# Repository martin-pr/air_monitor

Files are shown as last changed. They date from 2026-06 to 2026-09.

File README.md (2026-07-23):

# air_monitor
ESP32-based air monitor (CO2, temperature, humidity) with BLE notifications.
Ships in two firmware variants that share the sensor, BLE beacon protocol,
and Android widget:

- **display** — v1 hardware: e-paper dashboard, per-cycle full readout, charging inferred from battery voltage.
- **led** — v2 hardware: RGB status LED, momentary button, explicit USB charging detection. No display.

## Hardware

Shared across both variants:

- Seeed Studio XIAO ESP32-C3
- Sensirion SCD41 (CO2 / temperature / humidity, I2C)
- LiPo cell (400 mAh reference) with a 220 k / 220 k battery-voltage divider into `D0`

Display variant additionally uses:

- WeAct 200×200 ePaper module (SPI, SSD1681)

LED variant additionally uses:

- 5050 RGB LED (common-cathode assumed), three GPIO PWM channels through per-channel current-limiting resistors — 220 Ω red, 47 Ω green, 47 Ω blue
- Momentary push-button between a GPIO and GND, wired as a deep-sleep wake source
- VBUS-to-GPIO voltage divider for explicit "USB plugged in" detection (see wiring below)

## Prerequisites (one-time)

Install arduino-cli (official 64-bit binary, not the snap):

```bash
curl -fsSL https://raw.githubusercontent.com/arduino/arduino-cli/master/install.sh | sh
```

Install the ESP32 board package and required libraries:

```bash
arduino-cli core update-index
arduino-cli core install esp32:esp32
arduino-cli lib install "Sensirion I2C SCD4x"
# display variant only:
arduino-cli lib install GxEPD2
arduino-cli lib install "Adafruit GFX Library"
```

Grant serial port access:

```bash
sudo usermod -aG dialout $USER
# then log out and back in, or use: sg dialout -c "<command>"
```

## Build & Flash

```bash
cd firmware
cmake -B build
```

Build one variant, or both:

```bash
cmake --build build --target build_display
cmake --build build --target build_led
cmake --build build             # both variants
```

Flash to the device:

```bash
cmake --build build --target flash_display
cmake --build build --target flash_led
```

To override the upload port or target a different board:

```bash
cmake -B build -DPORT=/dev/ttyACM1
cmake -B build -DFQBN=esp32:esp32:XIAO_ESP32S3
```

The default FQBN is `esp32:esp32:XIAO_ESP32C3`.

### Source layout

```
firmware/
├── common/          Arduino library shared by both variants
│   └── src/         battery, ble, reset_reason, sensor
├── display/         e-paper sketch (display.ino, app.cpp, display.cpp)
└── led/             LED sketch (led.ino, app.cpp, plus led/button/charging modules)
```

## Serial Monitor

```bash
arduino-cli monitor -p /dev/ttyACM0 -c baudrate=115200
```

Press Enter once after connecting — the USB-Serial-JTAG peripheral requires the host to send a byte before output appears. This is default arduino-esp32 3.x behavior.

## Android Widget

The `app` directory contains an Android home-screen widget. It passively scans for BLE advertisements from the device and displays the latest sensor readings — no connection or pairing required.

The build uses Gradle with the Android Gradle Plugin. The wrapper is checked in, so no system Gradle install is needed — just JDK 17 and the Android SDK (build-tools 35, platform android-35). Point `local.properties` at the SDK on first checkout:

```bash
cd app
echo "sdk.dir=$HOME/Android/Sdk" > local.properties
```

Build the debug APK:

```bash
./gradlew :app:assembleDebug
# → app/build/outputs/apk/debug/app-debug.apk
```

Build the release AAB (for Google Play upload):

```bash
./gradlew :app:bundleRelease
# → app/build/outputs/bundle/release/app-release.aab
```

Release signing is driven by `keystore.properties` at the repo root (git-ignored). When it's present and points at an upload keystore, release builds are signed with it; when it's absent, they fall back to the debug keystore — fine for local test builds but rejected by Play.

Install a debug build on a connected Android device:

```bash
adb install -r app/build/outputs/apk/debug/app-debug.apk
```

After installing, add the **Air Monitor** widget from the Android launcher widget picker.

## BLE

The device uses a **connectionless beacon** — no GATT, no pairing. It wakes from deep sleep every 5 minutes, takes a measurement, updates the display (display variant) or flashes the status LED (LED variant), then advertises for 5 seconds before going back to sleep.

The advertisement contains manufacturer-specific data with company ID `0x4D41` (`AM`, little-endian bytes `0x41 0x4D`), followed by a versioned binary payload:

| Byte offset (after company ID) | Field | Type | Notes |
|---|---|---|---|
| 0 | Protocol version | uint8 | Currently `1`; check before parsing further fields |
| 1 | Status | uint8 | Last `esp_reset_reason_t`. `8` = normal wake from deep sleep; any other value means the chip cold-booted (see table below) |
| 2–3 | CO2 | uint16 LE | ppm |
| 4–5 | Temperature | int16 LE | 0.01 °C (e.g. 2350 = 23.50 °C) |
| 6 | Relative humidity | uint8 | % RH (integer) |
| 7 | Battery | uint8 | `0–100` = battery %; `0xFF` = charging. Detected via Vbat > 4.10 V threshold (display variant) or an explicit VBUS-divider ADC (LED variant); the % is unreliable during a charge cycle so we send a sentinel instead |

**Parsing rule:** read byte 0 first; only parse further fields if the version is known. The protocol is still under development — the version byte is bumped on any layout change rather than maintaining backward compatibility.

#### Status (reset reason) values

The raw `esp_reset_reason_t` enum is exposed as-is. The interesting values for this firmware:

| Value | Name | Meaning |
|---|---|---|
| 0 | `ESP_RST_UNKNOWN` | Reason could not be determined |
| 1 | `ESP_RST_POWERON` | Cold boot — USB plugged in, battery connected, or RESET button |
| 3 | `ESP_RST_SW` | Software-triggered `esp_restart()` (not used by this firmware) |
| 4 | `ESP_RST_PANIC` | Firmware crash (exception / abort) |
| 5 | `ESP_RST_INT_WDT` | Interrupt watchdog fired |
| 6 | `ESP_RST_TASK_WDT` | FreeRTOS task watchdog fired |
| 7 | `ESP_RST_WDT` | RTC watchdog (other) |
| 8 | `ESP_RST_DEEPSLEEP` | **Normal** — woke from `esp_deep_sleep()` |
| 9 | `ESP_RST_BROWNOUT` | Vbat sagged below the brownout threshold |
| 11 | `ESP_RST_USB` | USB peripheral triggered reset |
| 12 | `ESP_RST_JTAG` | JTAG triggered reset |

Values not in this table can still appear (`ESP_RST_EFUSE = 13`, `ESP_RST_PWR_GLITCH = 14`, `ESP_RST_CPU_LOCKUP = 15`, `ESP_RST_SDIO = 10`, `ESP_RST_EXT = 2`) — they're unlikely on this hardware/firmware but should be passed through unchanged.

The device advertises as **Air Monitor** (MAC `ac:27:6e:7e:c7:f4`). Scanners can filter by local name or company ID.

## Wiring

### SCD41 (I2C) — both variants

| SCD41 pin | XIAO pin | GPIO |
|---|---|---|
| VDD | 3V3 | — |
| GND | GND | — |
| SDA | D4 | GPIO6 |
| SCL | D5 | GPIO7 |

A decoupling capacitor between VDD and GND is required for stable CO2 readings. The NDIR laser draws a brief high current spike; without sufficient capacitance the CO2 measurement fails while RH/temp continue to work. The tested working combination is a 10 µF ceramic and a 100 µF electrolytic in parallel.

### Battery (J1 + voltage divider) — both variants

A JST connector (J1) brings in the LiPo battery. Two 220 kΩ resistors (R1, R2) form a 1:2 voltage divider so the full battery voltage range fits within the ESP32-C3 ADC input range:

```
Battery+ ──[R2 220kΩ]──┬── D0 (GPIO2, ADC)
                        │
                    [R1 220kΩ]
                        │
                       GND
```

Read with ADC 11 dB attenuation (0–3.9 V input range). The quiescent current through the divider is 4.2 V / 440 kΩ ≈ 10 µA — negligible.

Voltage is converted to a battery percentage using a 4-point lookup table with linear interpolation between segments:

| % | Battery V | V at D0 |
|---|---|---|
| 100 | 4.20 | 2.10 |
| 80 | 3.98 | 1.99 |
| 20 | 3.52 | 1.76 |
| 0 | 3.00 | 1.50 |

The middle segment (20–80%) approximates the flat part of the LiPo discharge curve; the steeper drops at each end get their own segments.

### ePaper Display (SPI) — display variant only

The WeAct 200×200 module connects over SPI. Despite the silkscreen labels (SCL/SDA), these are SPI signals — not I2C.

| WeAct pin | XIAO pin | GPIO |
|---|---|---|
| VCC | 3V3 | — |
| GND | GND | — |
| SDA | D10 | GPIO10 (MOSI) |
| SCL | D8 | GPIO8 (SCK) |
| CS | D3 | GPIO5 |
| D/C | D2 | GPIO4 |
| RES | D1 | GPIO3 |
| BUSY | D6 | GPIO21 |

Pins D7 and D9 remain free after this wiring.

The display is driven by [GxEPD2](https://github.com/ZinggJM/GxEPD2) using the `GxEPD2_154_D67` driver class.

### RGB LED (PWM) — LED variant only

A common-cathode 5050 RGB LED, one GPIO per channel, driven by ESP32-C3 LEDC PWM. Per-channel current-limiting resistors size the drive current so R / G / B contribute roughly equally at equal duty:

| Channel | XIAO pin | Series R | Current at full duty | Notes |
|---|---|---|---|---|
| Red | D6 | 220 Ω | ~5.9 mA | V_f ≈ 2.0 V, plenty of headroom |
| Green | D3 | 47 Ω  | ~6.4 mA | V_f ≈ 3.0 V, current sensitive to part-to-part V_f drift |
| Blue  | D2 | 47 Ω  | ~6.4 mA | Same as green |

```
D6 ──[220 Ω]── R anode ──┐
D3 ──[47 Ω] ── G anode ──┼── common cathode ── GND
D2 ──[47 Ω] ── B anode ──┘
```

Firmware never drives at 100 % duty — LED is used for brief low-brightness status flashes. Average current is deep-sleep-noise level, so no need to worry about brownout on turn-on transients.

### Button — LED variant only

Momentary tactile switch from a GPIO to GND, with the internal pull-up enabled on that pin. Wired as an RTC-capable pin so a press wakes the chip from deep sleep.

```
D7 ──┬── button ── GND
      │
      └── (internal pull-up)
```

### Charging-detect divider — LED variant only

Rather than inferring charging from Vbat > 4.10 V (the display variant's approach), the LED board has a dedicated divider off USB VBUS into a second ADC pin. VBUS is 5 V when USB is plugged in, 0 V otherwise; a 220 k / 220 k divider brings that to ~2.5 V, easily distinguished from 0 V by an ADC read.

```
VBUS ──[220 kΩ]──┬── D1 (GPIO3, ADC)
                  │
              [220 kΩ]
                  │
                 GND
```

Same resistor values as the battery divider — one BOM entry, shared design.

## Power

### Architecture

Both variants use a **deep sleep beacon** cycle:

1. Wake from deep sleep (timer, or button press on LED variant)
2. Take SCD41 single-shot measurement (~5 s)
3. Update display (display variant) or flash status LED (LED variant)
4. Advertise BLE beacon for 5 s
5. Deep sleep for ~5 minutes

Total active time: ~11 s per 300 s cycle.

### Component current

| Component | Mode | Current |
|---|---|---|
| ESP32-C3 | Deep sleep | ~5 µA |
| ESP32-C3 | Active, 80 MHz, no radio | ~20 mA |
| ESP32-C3 | BLE advertising burst | ~30 mA peak |
| SCD41 | Single-shot (5 min interval average) | ~0.5 mA |
| SCD41 | Power-down | <0.001 mA |
| ePaper (display variant) | Update (active) | ~20 mA |
| ePaper (display variant) | Hibernate | <0.01 mA |
| RGB LED (LED variant) | ~10 % duty, brief flash | ~2 µA averaged over the 5 min cycle |

### Battery estimate (400 mAh cell)

Active ~11 s per 300 s cycle, deep sleep otherwise. Averaged over a full cycle:

- ESP32-C3 active: ~25 mA × (11/300) ≈ 0.9 mA
- SCD41 single-shot: ~0.5 mA average (per datasheet at 5 min interval)
- Deep sleep (everything): ~5 µA × (289/300) ≈ negligible
- Display refresh (display variant only): dominated by ESP32-C3 active time, not the ePaper itself
- LED signalling (LED variant only): negligible (~2 µA averaged)

**Total ≈ 1.4 mA average → ~12 days on 400 mAh** for either variant (excluding deep sleep current anomalies under investigation). The LED variant should be marginally better since ePaper refresh time shrinks to zero, but the ESP32-C3 active window still dominates the budget.

### SCD41 single-shot and ASC

The firmware uses `measure_single_shot` (not periodic mode). The sensor stays idle until triggered, takes ~5 s for a reading, then enters power-down. The ESP32 controls the interval.

Automatic Self-Calibration (ASC) works with single-shot via the `power_down` / `wake_up` command pair, which preserves calibration state in SRAM. Hard VDD power-cycling breaks ASC because SRAM is lost. The datasheet optimises ASC for a 5-minute interval and requires outdoor-level CO2 (~400 ppm) exposure at least once per week.

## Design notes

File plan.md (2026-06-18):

# Power Reduction Plan

## Target

- Battery: 450 mAh
- Required runtime: 2 weeks
- Average current budget: **1.34 mA**

## Why the current architecture cannot meet the target

The device currently averages ~50 mA with BLE always advertising. Even with every available always-on optimization, the math does not work:

| Architecture | Avg current | Battery life |
|---|---|---|
| Current (always-on BLE, no sleep) | 50 mA | ~9 hours |
| BLE modem sleep, fully tuned | 5-8 mA | 2-3 days |
| Deep sleep, 30s wake interval | ~4 mA | ~4 days |
| Deep sleep, 2 min wake interval | ~2 mA | ~9 days |
| Deep sleep, 5 min wake interval | ~1 mA | ~18 days |

The BLE controller on ESP32-C3 holds a `NO_LIGHT_SLEEP` pm lock while active, so any architecture that keeps BLE up continuously is bounded by the radio's idle current. Deep sleep between measurements is the only path that meets the budget.

Confirmed empirically: with `BLE_ENABLED = false` the device draws 22 mA (light sleep not engaging due to USB-JTAG pm lock); with BLE on, 50 mA. Neither is close to 1.34 mA.

## Chosen architecture: deep sleep + BLE beacon

1. Wake from deep sleep
2. Take SCD41 single-shot measurement (~5s)
3. Update e-paper display (~1.5s)
4. Emit advertising packets with reading encoded in manufacturer data (~5s)
5. Deep sleep for the remainder of the cycle (~5 µA)

Reading carried in the advertisement payload — no GATT connection needed. Phone scans and parses.

## Existing work: `beacon_mode` branch

This architecture is mostly implemented on the `beacon_mode` branch:

- `esp_deep_sleep()` with 1-minute cycles
- SCD41 single-shot mode with proper wake/measure/powerDown sequencing
- Manufacturer-data beacon: company ID `0x4D41` ('AM'), 7-byte versioned payload (version, CO2, temp×100, RH, battery%)
- 5-second advertising window at 100 ms interval
- `Wire.end()`, `SPI.end()`, GPIO10 floated before sleep
- Android app rewritten to scan-and-parse instead of connect-and-subscribe

## Open issues to resolve

### 1. ~~Display bug: empty after 2nd refresh~~ (fixed)

Fixed via `display.epd2.writeScreenBufferAgain()` after the initial clear plus the buffered `showStatus` rewrite. Plus `showStatus(rstMsg)` so the reset reason becomes line 1 in the buffer rather than being clobbered by the first status update.

### 2. Android background reception unreliable

The core blocker. A normal `startScan()` callback does not fire when the screen is off because of Android's Doze and background scan throttling. Three paths forward, in order of preference for a widget use case:

**Option A — PendingIntent-based scanning (API 26+).** Use the `BluetoothLeScanner.startScan(filters, settings, callbackIntent)` overload. The system holds the filter, scans on its own schedule, and wakes the app via the intent on a match — including from Doze.
- Pros: no foreground service, no persistent notification, designed for exactly this case.
- Cons: requires `ACCESS_BACKGROUND_LOCATION` on Android 10+. Some OEM power managers (Xiaomi, Huawei) kill it.
- Phone battery impact: **~0.5-1% per day**. The system batches scans and the app only wakes on match (once per sensor cycle); each wake is ~50-100 ms of CPU plus a brief intent dispatch.

**Option B — Foreground service with persistent notification.** A foreground service is exempt from Doze scanning restrictions; `startScan` callback runs continuously.
- Pros: most reliable across all OEMs.
- Cons: permanent status-bar notification.
- Phone battery impact: **~5-15% per day**. Continuous BLE scanning is expensive (BT subsystem stays in the 3-15 mA range depending on scan mode), and the service prevents the app process from being killed, so any callbacks/work executed per scan result accumulate.

**Option C — Connection-oriented with `autoConnect=true`.** Device wakes, advertises, accepts a short GATT connection, sends the reading, disconnects, sleeps. Phone uses `connectGatt(autoConnect=true)` which makes Android handle the wait-and-connect at the system level.
- Pros: very reliable on Android.
- Cons: device awake longer (~10-15s instead of ~5s), modestly higher average current.
- Phone battery impact: **~1-3% per day**. The system handles the pending-connection efficiently; brief radio activity (~1-2s per sensor cycle) when the device shows up.

Numbers are rough — actual impact varies with phone hardware, Android version, and other background scanners. For reference, a typical phone uses 0.5-1% per hour in standby, so option A or C adds noise-level overhead while option B is genuinely noticeable.

Decision pending. Current `BleWidgetService.java` (merged from beacon_mode) implements option B — foreground service with `SCAN_MODE_LOW_LATENCY` and `MATCH_MODE_AGGRESSIVE`. Confirmed unreliable when the screen is locked, so this implementation must change regardless. Option A or C is the way forward.

## Measured progress

All numbers measured on hardware: battery-powered, USB disconnected, average current over a steady-state 1-minute cycle (after first boot completes). `beacon_mode` has been merged into `main`.

| Firmware state | Avg current | Battery life | Per-cycle energy |
|---|---|---|---|
| Cherry-picked beacon_mode baseline | 8.8 mA | 2.1 days | 528 mAs |
| SCD41 5s wait → `esp_light_sleep_start()` (`df427b1`) | 7.74 mA | 2.4 days | 464 mAs |
| Drop `WiFi.mode(WIFI_OFF)` + 200ms delay | 7.33 mA | 2.55 days | 440 mAs |

Per-cycle active energy is ~380 mAs over a ~14 s active phase (about 27 mA average during active). The 5 s BLE advertising window is the largest single chunk.

### Sleep current is *not* negligible — 1.29 mA measured

Direct measurement of the deep-sleep floor: **1.29 mA**, three orders of magnitude higher than the ~5 µA the ESP32-C3 datasheet suggests. Isolation testing:

| Configuration | Sleep current |
|---|---|
| Full board (XIAO + display + SCD41 + battery divider) | 1.29 mA |
| Display module disconnected | 232 µA |
| → Display module contribution | **~1.06 mA** |

The e-paper module is drawing ~1 mA continuously during sleep despite `display.hibernate()` and `SPI.end()`. The SSD1681 chip itself in deep sleep is ~5 µA, so this is module-level circuitry on the breakout PCB (boost/charge-pump glue, level shifters, or leakage paths through floating data pins on the SSD1681). The remaining 232 µA floor (no display) is XIAO + SCD41 breakout + ESP32-C3's real-world deep-sleep being higher than datasheet — secondary concern.

### Battery-life projections must include sleep current

With sleep dominant at longer cycles, the math changes dramatically. Per-cycle energy = ~380 mAs active + sleep current × sleep duration:

| Cycle | Sleep at 1.29 mA (today) | Sleep at 232 µA (display power-gated) |
|---|---|---|
| 1 min | 7.33 mA → 2.55 d (measured) | ~6.5 mA → 2.9 d |
| 5 min | 2.50 mA → 7.5 d | 1.49 mA → 12.6 d |
| 6 min | 2.29 mA → 8.2 d | 1.28 mA → 14.7 d ✓ |
| 10 min | 1.89 mA → 9.9 d | 0.86 mA → 21.8 d |
| 15 min | 1.69 mA → 11.1 d | 0.65 mA → 28.8 d |
| ∞ (sleep only) | **1.29 mA → 14.5 d (ceiling)** | 0.232 mA → 80+ d |

**At 1.29 mA sleep, no cycle length reaches 2 weeks** — sleep current alone consumes the budget. The display power-gating must be solved before any cycle-tuning matters.

### Notes on optimizations attempted/considered

- `display.hibernate()` between updates: kept (still correct), but power impact was much smaller than the SSD1681 datasheet suggested. Most of the visible refresh time is the e-ink material settling at low current, not the voltage pump.
- Shortening `ADV_DURATION_MS` (5 s → 2 s): not yet applied — would save ~90 mAs/cycle but couples to the (still-undecided) Android reception strategy. Safe under foreground scanning (option B), risky under PendingIntent (option A) or short-window autoConnect (option C).
- CPU frequency dance (drop to 40 MHz outside the BLE phase): not applied. BLE requires ≥80 MHz on ESP32-C3; dropping for the non-BLE phase would save ~50 mAs/cycle but adds complexity (APB clock divides change, affecting SPI/I2C timing).
- `esp_bt_sleep_enable()` before advertising: not tried yet — unknown gain, low risk.

### Display sleep-current fix options

1. ~~**Software — float all display pins (CS, DC, RST, SCK, MOSI) before deep sleep.**~~ Tried, no effect (1.29 → 1.30 mA). Leakage is not through SSD1681 input pins.
2. ~~**Software — switch SSD1681 from deep sleep mode 1 to mode 2** (RAM not retained, deeper sleep).~~ Tried via raw SPI `0x10 0x11` after `hibernate()`, no effect (1.30 mA). Module-level leakage is independent of SSD1681 sleep depth.
3. ~~**Software — hold `EPD_RST` low through deep sleep via `gpio_hold_en()`**~~ on the chance the breakout's boost EN piggybacks off RST. Tried, *worse* (1.36 mA): the boost is not gated by RST, and holding the GPIO output + putting the chip in hardware reset both cost a small amount.

All three software paths confirmed dead. The module's quiescent draw is from its own onboard circuitry (boost converter / glue), independent of any SSD1681 pin or state. **Hardware power-gating is the only remaining option.**

4. **Hardware — high-side P-channel MOSFET load switch on the display VCC.** Gate driven by a GPIO; drive high to cut power before sleep, low to enable on wake. ~3 components (MOSFET + pull-up + GPIO). Fully power-gates the module → 0 µA from display in sleep. The only viable fix for the display variant.

5. **Build a no-display variant.** If the display isn't a hard requirement, omitting it sidesteps the problem entirely — no board revision needed. See below.

### Alternative: no-display variant meets the goal as-is

Removing the e-paper module entirely (or fitting a hardware variant without it) gives a 232 µA sleep floor with no further engineering. The active phase also drops by ~30–50 mAs/cycle (no display init / full-window refresh / hibernate).

Estimated active phase: ~340–360 mAs/cycle (vs ~380 mAs with display).

| Cycle | Avg current | Battery life |
|---|---|---|
| 1 min | ~6.0 mA | ~3 days |
| 5 min | ~1.40 mA | ~13.4 days |
| **6 min** | **~1.20 mA** | **~15.6 days ✓** |
| 10 min | ~0.81 mA | ~23 days |
| 15 min | ~0.60 mA | ~31 days |

A 6-minute cycle on the no-display variant hits 2 weeks with margin; 10-minute gives 3 weeks. Since there's no visual refresh, longer cycles are free — the phone gets readings from the beacon regardless of cadence.

The 232 µA floor still has ~225 µA of unexplained draw (vs ESP32-C3 datasheet ~5 µA deep sleep). Likely from the SCD41 breakout pull-ups and the C3's real-world deep sleep being higher than spec. Could be chased further but isn't needed for the 2-week target.

## Next steps

Two parallel paths depending on whether the display is a hard requirement:

**Display-required path:**
1. Design the MOSFET load switch on the next PCB revision (display VCC power-gated by a GPIO).
2. Once display sleep current is fixed, tune `SLEEP_DURATION_US` to the cycle length that meets the budget.

**No-display variant:**
1. Measure actual active-phase energy with the display removed to confirm the ~340-360 mAs estimate.
2. Set `SLEEP_DURATION_US` to 6 minutes (or longer for more margin).

**Both paths:**
3. Pick A / B / C for Android reception.
4. Implement chosen Android approach.

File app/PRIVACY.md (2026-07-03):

# Privacy Policy

**Last updated:** July 2, 2026

Air Monitor is an open-source Android home-screen widget for displaying
sensor readings from an ESP32-based air monitor.

The app passively scans for Bluetooth Low Energy (BLE) advertisements
from the device and displays the latest sensor readings. It does not
connect to, pair with, or transmit data to the device.

## Information Collection

Air Monitor does not collect, store, transmit, sell, or share personal
information.

The app does not use: - Analytics - Advertising - User accounts -
Tracking technologies - Backend servers - Firebase - Crashlytics - Cloud
services operated by the developer

## Local Operation

Any data shown by the app is received locally on the user's device from
nearby BLE advertisements and is used only to display air-monitor
readings.

## Google Play

The app is distributed through Google Play. Google may collect
information related to app download, installation, updates, crash
reporting, and Play Store usage under Google's own privacy policies. The
developer may only receive aggregated information made available through
Google Play Console.

## Open Source

Source code: https://github.com/martin-pr/air_monitor

## Contact

Questions or issues can be raised on the GitHub repository.

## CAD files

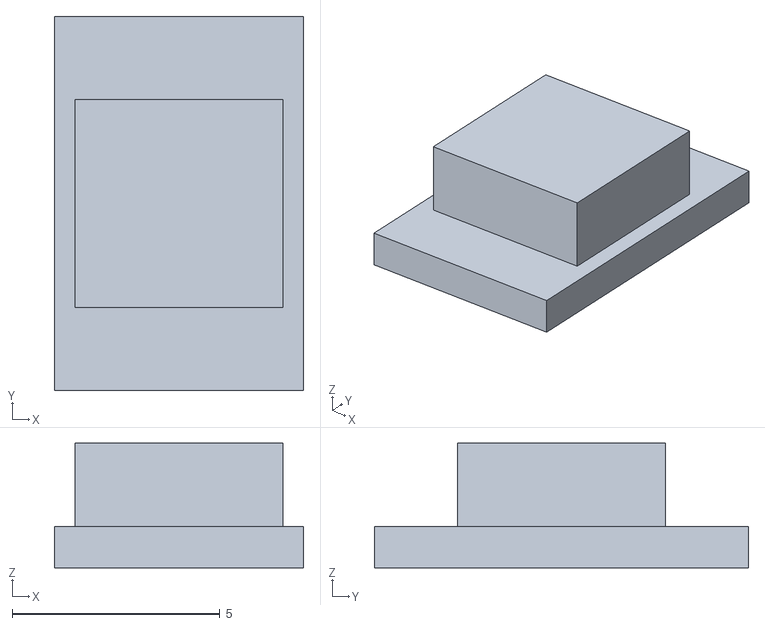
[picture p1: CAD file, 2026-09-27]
enclosure/enclosure_v2_windows.stl
6.00 x 9.00 x 3.00

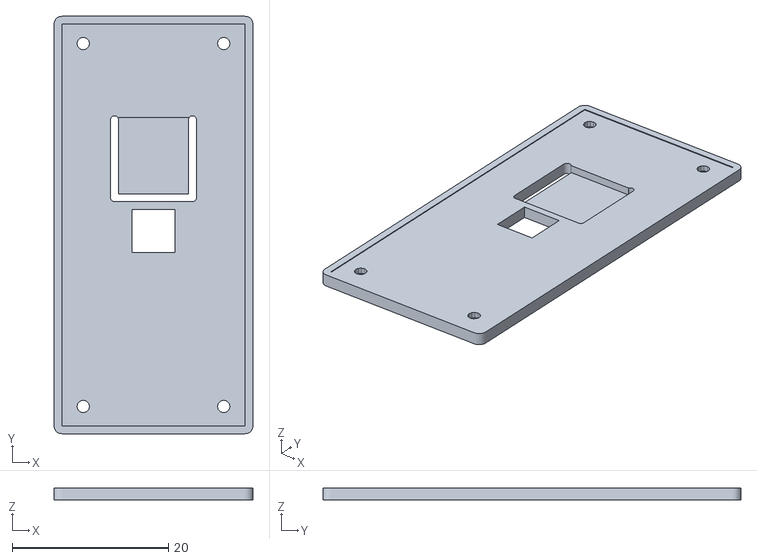
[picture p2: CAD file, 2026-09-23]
enclosure/enclosure_v2_top.stl
25.5 x 53.5 x 1.60

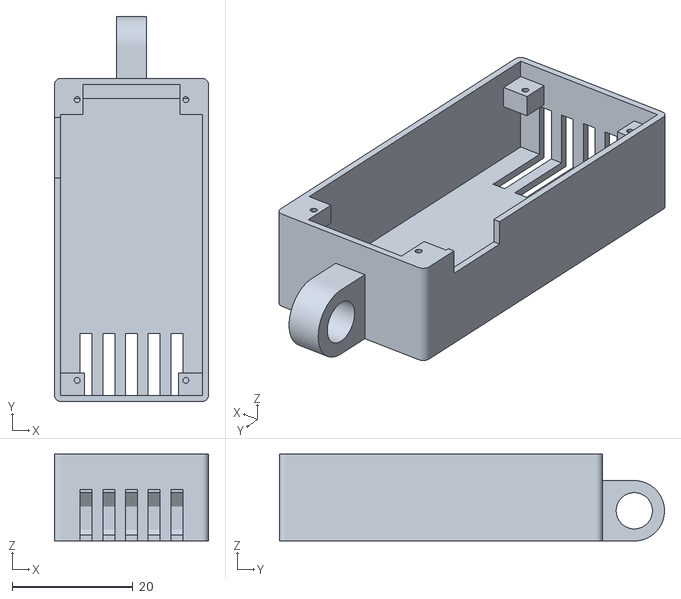
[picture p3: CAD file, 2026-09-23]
enclosure/enclosure_v2.stl
25.5 x 63.8 x 14.4

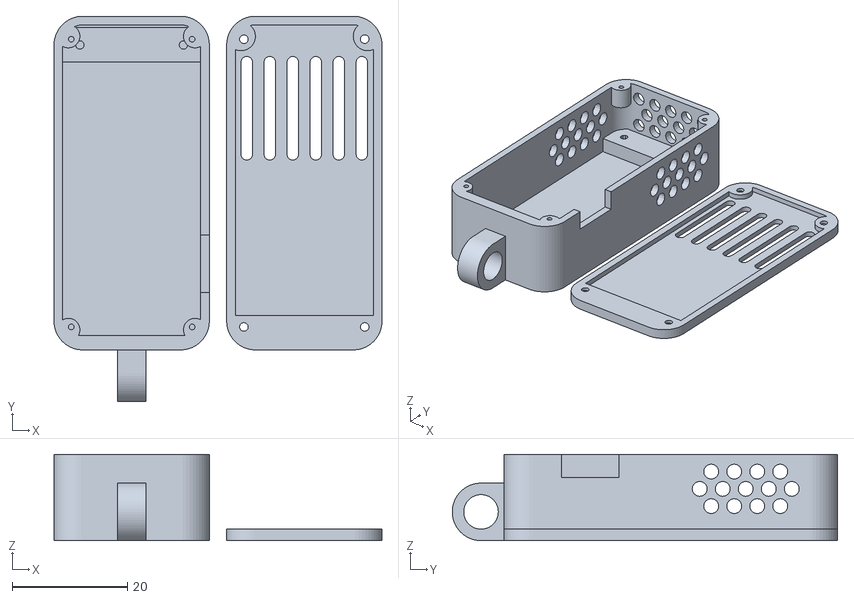
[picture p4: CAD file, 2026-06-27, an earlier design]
enclosure/enclosure.stl
57.0 x 67.0 x 15.0

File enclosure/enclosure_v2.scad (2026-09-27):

// 23.5 x 51.5r x 12

module bottom() union() {
    difference() {
        union() {
            minkowski() {
                cube([23.5, 51.5, 14], center=true);
                cylinder(d=2, h=2,  center=true, $fn=20);
            }        
        }
        
        cube([23.5, 51.5, 14], center=true);
        translate([0,0,9.4]) cube([26, 55, 6], center=true);
        
        translate([7.5,-23,-5]) cube([2, 15, 11], center=true);
        translate([3.75,-23,-5]) cube([2, 15, 11], center=true);
        translate([0,-23,-5]) cube([2, 15, 11], center=true);
        translate([-3.75,-23,-5]) cube([2, 15, 11], center=true);
        translate([-7.5,-23,-5]) cube([2, 15, 11], center=true);
        
        translate([-12,15.25,4.91]) cube([5,10,4], center=true);
    }

    translate([9,-23.25,2.5]) difference() {
        translate([1,-1,0]) cube([4.5, 4.5, 3], center=true);
        cylinder(r=0.5, h=20, center=true, $fn=12);
    }        

    translate([-9,-23.25,2.5]) difference() {
        translate([-1,-1,0]) cube([4.5, 4.5, 3], center=true);
        cylinder(r=0.5, h=20, center=true, $fn=12);
    }    

    translate([0,24,-3.5]) difference() {
        cube([25, 3.5, 7], center=true);
        translate([0,,-2]) rotate(45, [1,0,0]) cube([25, 7, 9], center=true);
    }    

    translate([0,23.25,5]) difference() {
        cube([25, 5, 2.8], center=true);
        translate([9,0,0]) cylinder(r=0.5, h=20, center=true, $fn=12);
        translate([-9,0,0]) cylinder(r=0.5, h=20, center=true, $fn=12);
        cube([16, 6, 3], center=true);
    }   
   
    translate([0,32,-3]) {
        difference() {
            hull() {
                rotate(90, [0,1,0]) cylinder(r=5, h=5, center=true, $fn=64);
                translate([0,-3,0]) cube([5,5,10], center=true);
            }
            
            rotate(90, [0,1,0]) cylinder(r=3, h=7, center=true, $fn=64);
        }
    }    
}

 module hole() {
     translate([0, 0, 7.75]) cylinder(r=1.5, h=1, center=true, $fn=12);
     translate([0, 0, 6.95]) cylinder(r=0.8, h=5, center=true, $fn=12);
 }

 //translate([40,-26.75,0]) cube([10,21,15]);
//translate([40,0,0]) translate([0,-26.75,0]) cube([10,27.5,15]);
// translate([40,0,0]) translate([0,0.75,0]) cube([5,5,15], center=true);

module corner() cylinder(d=1, h=5, center=true, $fn=32);

module top() difference() {
    intersection() {
        
        difference() {
            minkowski() {
                cube([23.5, 51.5, 14], center=true);
                cylinder(d=2, h=2,  center=true, $fn=20);
            }        
            cube([23.5, 51.5, 13], center=true);
        }
        translate([0,0,7.4]) cube([26, 55, 2], center=true);
    }
    
    translate([9,-23.25,0]) hole();
    translate([-9,-23.25,0]) hole();
    
    translate([0,23.25,0]) {
        translate([9,0,0]) hole();
        translate([-9,0,0]) hole();
    }

    translate([0,0.75,0]) cube([5.5,5.5,18], center=true);
    
    translate([0, -8.75, 0]) cube([10,10,15], center=true);
    
    translate([0, -3.5, 6.95]) hull() {
        translate([-5,0,0]) corner();
        translate([5,0,0]) corner();
    };

    translate([0, -3.5, 6.95]) hull() {
        translate([-5,0,0]) corner();
        translate([-5,-10,0]) corner();
    };
    
    translate([0, -3.5, 6.95]) hull() {
        translate([5,0,0]) corner();
        translate([5,-10,0]) corner();
    };
}

module led(size, rim_y=4, rim_x=1) union() {
    translate([-size/2, -size/2, 0]) cube([size,size,3]);
    translate([(-size-rim_x)/2, (-size-rim_y)/2, 0]) cube([size+rim_x,size+rim_y,1]);
}

// bottom();
// rotate(180, [1,0,0]) translate([20,0,-8]) top();

led(5);

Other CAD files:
enclosure/enclosure.scad

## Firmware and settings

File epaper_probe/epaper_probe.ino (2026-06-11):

#include <SPI.h>
#include <GxEPD2_BW.h>
#include <Fonts/FreeSans9pt7b.h>

#define EPD_CS   5
#define EPD_DC   4
#define EPD_RST  3
#define EPD_BUSY 21
#define SPI_SCK  8
#define SPI_MOSI 10
#define SPI_MISO 9

GxEPD2_BW<GxEPD2_154_D67, GxEPD2_154_D67::HEIGHT> display(
    GxEPD2_154_D67(EPD_CS, EPD_DC, EPD_RST, EPD_BUSY)
);

void drawTest(const char *label) {
    display.setFullWindow();
    display.firstPage();
    do {
        display.fillScreen(GxEPD_WHITE);
        display.setTextColor(GxEPD_BLACK);
        display.setFont(&FreeSans9pt7b);
        display.setCursor(10, 60);
        display.print("GxEPD2_154_D67");
        display.setCursor(10, 90);
        display.print(label);
        display.fillRect(10, 110, 180, 40, GxEPD_BLACK);
    } while (display.nextPage());
}

void setup() {
    Serial.begin(115200);
    delay(3000);  // wait for USB-JTAG to attach
    Serial.println("=== ePaper probe start ===");

    Serial.printf("BUSY pin %d state before init: %d\n", EPD_BUSY, digitalRead(EPD_BUSY));

    SPI.begin(SPI_SCK, SPI_MISO, SPI_MOSI, EPD_CS);
    Serial.println("SPI.begin done");

    display.init(115200, true, 10, false);
    Serial.println("display.init done");

    Serial.printf("BUSY pin %d state after init: %d\n", EPD_BUSY, digitalRead(EPD_BUSY));

    Serial.println("drawing test frame...");
    drawTest("Hello!");
    Serial.println("draw done");
}

void loop() {
    delay(10000);
    Serial.println("still alive");
}

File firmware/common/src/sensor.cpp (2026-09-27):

#include "sensor.h"

#include <Arduino.h>
#include <Wire.h>

Sensor::Sensor(bool firstBoot, const Config& config) {
    Wire.begin(config.sdaPin, config.sclPin);
    _sensor.begin(Wire, SCD41_I2C_ADDR_62);
    if (firstBoot) {
        _sensor.stopPeriodicMeasurement();
        delay(500);
        disableAutoCalibration();  // idle mode required — we're stopped here
    } else {
        _sensor.wakeUp();
        delay(30);  // datasheet: 30ms after wakeUp before issuing commands
    }
}

Sensor::~Sensor() {
    _sensor.powerDown();
    Wire.end();
}

void Sensor::startMeasurement() {
    _sensor.measureSingleShot();
}

Sensor::Reading Sensor::read() {
    Reading r{ 0, 0.0f, 0.0f };
    _sensor.readMeasurement(r.co2, r.temperature, r.humidity);
    return r;
}

void Sensor::disableAutoCalibration() {
    // ASC assumes the sensor regularly sees fresh ~400ppm air and rebaselines
    // toward it. In our infrequent single-shot use that assumption fails and
    // the reading drifts, so we keep ASC off and rely on manual calibrate()
    // (FRC) instead. Persisted to EEPROM so it survives power cycles; only
    // rewritten when actually still on, to spare the EEPROM's write endurance.
    uint16_t enabled = 1;
    if (_sensor.getAutomaticSelfCalibrationEnabled(enabled) != 0) return;
    if (!enabled) return;  // already off — don't burn an EEPROM write

    _sensor.setAutomaticSelfCalibrationEnabled(0);
    _sensor.persistSettings();  // writes EEPROM; the driver waits out the ~800ms
}

bool Sensor::calibrate(uint16_t referenceCo2) {
    // FRC is only valid in idle mode; make sure no periodic measurement is
    // running before issuing it (datasheet: stop, then recalibrate).
    _sensor.stopPeriodicMeasurement();
    delay(500);

    uint16_t frcCorrection = 0;
    int16_t error = _sensor.performForcedRecalibration(referenceCo2, frcCorrection);
    // 0xFFFF in the correction word means the sensor rejected the FRC because
    // it hadn't been operated in a stable environment beforehand.
    return error == 0 && frcCorrection != 0xFFFF;
}

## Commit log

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2026-05-23 Add BLE GATT server with random UUIDs
    Advertises as "Air Monitor", exposes a readable characteristic returning
    "hello world". UUIDs are randomly generated to avoid collisions with other
    devices. README documents the service and characteristic UUIDs.
2026-05-23 Switch to BLE notify with counter and LED blink on send
    Replaces polling read with NOTIFY characteristic. Device pushes
    "hello world N" every 2 seconds when a client is subscribed, blinks
    the LED on each send. Restarts advertising automatically on disconnect.
    LED_BUILTIN is active-low on XIAO ESP32-S3.
2026-05-23 Send JSON payload over BLE notify, increase MTU to 512
    Replaces plain string with ArduinoJson payload: {"id":N,"message":"hello world"}.
    Sets BLE MTU to 512 to avoid truncation. Converts #defines to constexpr.
    Uses std::string_view for UUIDs and std::array for the JSON buffer.
2026-05-23 Increase notify interval to 30s, yield CPU between checks
    Adds delay(10) in loop() to yield to FreeRTOS between millis() checks,
    avoiding busy-spin for the full 30-second idle period.
2026-05-23 Robust disconnect handling and advertising blink
    - Restart advertising via flag in loop() rather than directly in BLE
    callback to avoid silent failures
    - Blink LED once per second while advertising, stop when connected
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2026-05-30 Fix app getting stuck in disconnected state after external BLE connection
    Android has a quirk where a BLE scan that was running before a device
    started advertising can miss it even after it reappears. This happened
    when a tool like nRF Connect connected to the device (stopping its
    advertising), then disconnected — the app's scan would stay active but
    never pick up the device again without a phone restart.
    Fix: restart the scan every 3 minutes when not connected. The scan was
    already running continuously in low-power mode, so this adds no extra
    battery drain — it just cycles the scan to prevent it getting stale.
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2026-06-10 Integrate SCD41 sensor; use RHT-only mode until decoupling cap is added
    Adds SCD41 CO2/temperature/humidity sensor integration over I2C
    (SDA=GPIO6, SCL=GPIO7 on XIAO ESP32-C3). Uses measureSingleShotRhtOnly()
    instead of full periodic measurement because without a 100µF decoupling
    capacitor on VDD, the ~200mA CO2 laser spike causes the measurement to
    fail. RHT-only mode skips the NDIR laser and works reliably with the
    current hardware. CO2 can be re-enabled once a capacitor is added.
    JSON payload is now {"temp": 23.3, "rh": 56.8} instead of hello world.
2026-06-10 Switch SCD41 to low-power periodic mode now that decoupling cap is fitted
    Replaces the RHT-only single-shot workaround with the intended
    startLowPowerPeriodicMeasurement() mode. The sensor autonomously measures
    CO2/temp/RH every 30s; the firmware reads the result just before each BLE
    notification. Requires a decoupling capacitor on SCD41 VDD (100µF + 220µF
    fitted) to supply the ~200mA peak current during CO2 laser measurement.
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2026-06-10 Add ePaper driver probe sketch
    Minimal sketch used to identify the correct GxEPD2 driver class for the
    WeAct 200x200 module. Prints BUSY pin state and refresh timing over
    serial — GxEPD2_154_M09 completed in 1ms (wrong), GxEPD2_154_D67 took
    ~1.5s (correct full refresh).
    [epaper_probe.ino]
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2026-06-14 Add SCD4x datasheet and update README power figures with precise values
    Add docs/Sensirion_SCD4x_Datasheet.pdf as reference for hardware decisions.
    Update the power section with datasheet-accurate numbers: SCD41 low-power
    periodic is 3.2–3.5 mA, single-shot at 5-min intervals averages 0.45–0.5 mA
    (not the misleading "idle + burst" decomposition used before). Add the
    continuous periodic mode row (15–18 mA) which was missing. Correct the deep
    sleep battery estimate to ~14 days. Drop the "connected + single-shot" battery
    row — persistent BLE + single-shot is a contradiction in the current
    architecture. Add ASC implications (power_down/wake_up preserves calibration;
    hard VDD cycling doe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
2026-06-14 Fix README: D0 is used for battery ADC, not free
    The schematic connects D0/GPIO2 to a 220k+220k voltage divider from
    the battery connector for voltage monitoring.
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2026-06-15 Disable WiFi before BLE init to fix reset on 3.3V supply; add BLE_ENABLED flag
    WiFi and BLE share the same radio on ESP32-C3. Calling WiFi.mode(WIFI_OFF)
    before BLEDevice::init() eliminates the dual-radio calibration spike that was
    causing resets when powered from 3.3V. Also wraps all BLE code in a
    BLE_ENABLED compile-time flag for easier isolation testing.
2026-06-15 Fix BLE init resets on 3V3; decouple display refresh from BLE connection
    Interleaving partial display updates between BLE init steps prevents light
    sleep power-state transitions during radio calibration, which were causing
    brownout resets on 3.3V supply. Also sets a 1-1.25s advertising interval
    (vs default ~100ms) to reduce TX burst rate, and decouples display refresh
    from BLE connection state so readings update every 30s even without a client.
2026-06-16 Show reset reason on display at startup
    Adds esp_reset_reason() switch before the first BLE init step so
    brownout, panic, and watchdog resets are visible on the ePaper display
    without a serial connection.
2026-06-17 Refactor showStatus to buffer and redraw all lines; reorder SCD41 init
    showStatus now accumulates lines in a static array and redraws from
    scratch on each call with a growing partial window, fixing EPD ghosting
    from the previous one-line-at-a-time approach. Delays between updates
    spread power draw to avoid overwhelming the supply.
    SCD41 init moved to after display is up so boot diagnostics are visible
    before sensor startup stresses the rail. Add writeScreenBufferAgain()
    after initial clear to sync SSD1681 current/previous buffers. Add
    missing step label for GATT service creation.
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2026-06-18 Document power reduction plan and beacon-mode architecture decision
    Captures the analysis: 450 mAh battery + 2 week target → 1.34 mA budget,
    which always-on BLE can't meet even with full modem sleep. Deep sleep
    plus a manufacturer-data beacon (already prototyped on beacon_mode) is
    the only path that closes the math. Notes the two open issues on that
    branch — display refresh bug (already fixed on main) and Android
    background reception — and lays out PendingIntent / foreground service
    / autoConnect as the three Android reception options with phone battery
    impact estimates.
2026-06-18 Preserve reset reason on display through subsequent status updates
    The standalone full-window RST render and the first showStatus() call
    both wrote to roughly y=20, so the partial-window redraw in showStatus
    erased the reset reason. Route the reset reason through showStatus()
    itself so it becomes line 1 in the buffer and survives the redraws.
    Also restore writeScreenBufferAgain() + hibernate after the initial
    white fill (lost during the beacon_mode cherry-pick) to keep the
    SSD1681 current/previous buffers in sync before any partial update.
2026-06-18 Light-sleep through SCD41 single-shot wait instead of spinning CPU
    Replaces the 5s delay() after measureSingleShot() with esp_light_sleep_start()
    gated by a timer wakeup. Measured impact: 1-minute-cycle average drops from
    8.8 mA to 7.74 mA (~64 mAs saved per cycle, matching the predicted savings
    of ~13 mA × 5 s).
    BLE is not yet initialized at this point in the cycle, so light sleep is
    safe — the advertising-window delay still spins because arduino-esp32's BLE
    controller is configured with the main XTAL as the low-power clock, which
    keeps the chip awake during BLE activity.
2026-06-18 Drop WiFi.mode(WIFI_OFF) shutdown ritual
    After deep-sleep wake the WiFi peripheral is already in its default-off
    state, so calling WiFi.mode(WIFI_OFF) only spins up enough of the WiFi
    stack to issue the OFF command and then sleeps for 200 ms waiting for
    the shutdown. Removing both saves ~25 mAs per cycle (measured: 7.74 mA
    → 7.33 mA on a 1-minute cycle) and drops binary size from 94% to 50%
    of flash since the WiFi stack no longer needs to be linked in.
2026-06-18 Record measured power numbers and revise battery-life projections
    Logs the actual currents measured on hardware (8.8 → 7.74 → 7.33 mA
    average over a 1-minute cycle) and the per-cycle active energy
    (~440 mAs). Marks the display-refresh-after-2nd-update bug as fixed
    and notes the merged BleWidgetService.java is the worst Android
    option (foreground service + LOW_LATENCY scan) and must change.
2026-06-18 Capture sleep-current finding: 1.29 mA floor, dominated by display
    Measured deep-sleep current directly — 1.29 mA, not the µA-scale value
    the architecture math assumed. Isolation testing: with the e-paper
    module disconnected the floor drops to 232 µA, so ~1 mA is leaking
    through the display module despite display.hibernate() + SPI.end().
    Reworks the battery-life projection table to include the sleep
    contribution and shows that at 1.29 mA sleep no cycle length reaches
    the 2-week target — sleep current alone consumes the budget. Adds
    display sleep-current fix options (drive pins low, P-MOSFET load
    switch) and reorders next steps so the display issue blocks
    cycle-tuning.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
2026-06-18 Record that software pin-floating doesn't fix display sleep current
    Tried explicitly floating CS, DC, RST, SCK, MOSI before deep sleep on
    the hypothesis that the leakage was through SSD1681 input buffers.
    Measured: 1.29 mA → 1.30 mA. No effect. The leakage is module-level
    circuitry (boost / glue components) that stays powered as long as the
    display VCC is connected, so a high-side MOSFET load switch is the
    only viable fix. Rules software paths out of further consideration.
2026-06-18 Rule out two more display-sleep software paths; hardware is the only fix
    Tried SSD1681 deep sleep mode 2 (raw 0x10 0x11 instead of GxEPD2's mode 1)
    and holding EPD_RST low through deep sleep via gpio_hold_en(). Mode 2
    made no difference (1.30 mA). RST-hold made things slightly worse
    (1.36 mA) — boost is not gated by RST, and holding the GPIO + putting
    the chip in hardware reset both cost a small amount.
    All three software hypotheses (pin float, deep sleep mode, RST hold) are
    now confirmed dead. The module's ~1 mA quiescent is fundamentally from
    onboard circuitry that's only controllable by cutting VCC. A MOSFET load
    switch on the next board revision is the only remaining fix.
    Co-Authored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
2026-06-18 Switch Android widget to PendingIntent-based BLE scanning
    Replaces the foreground-service + LOW_LATENCY-callback approach (option
    B in plan.md, the worst on every axis) with a system-managed
    PendingIntent scan (option A). The system holds the scan filter on our
    behalf and delivers matched beacons via BeaconScanReceiver — works in
    Doze, no persistent notification, no foreground service, and uses
    SCAN_MODE_LOW_POWER since the sensor only beacons every minute.
    Splits the old BleWidgetService into:
    - BeaconScanReceiver: scan registration + onReceive decode
    - WidgetState: SharedPreferences-backed reading + widget rendering
    (persistence matters now because PendingIntent may deliver to a
    fre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
2026-06-18 Declare widget eligible for the keyguard category
    Adds 'keyguard' to widgetCategory so the widget becomes pickable by any
    host that respects the standard AppWidget lock screen category. Stock
    Android no longer hosts lock screen widgets, and Samsung One UI's
    current lock screen widget framework uses a separate private FaceWidget
    API (not the standard widgetCategory), so this has no effect on current
    devices. Samsung is reportedly opening standard third-party lock screen
    widget support in One UI 8 / Android 16, at which point this change
    makes the widget available on Samsung's lock screen with no further
    work. Forward-compatible no-op until then.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
2026-06-18 Show latest reading as a persistent lock-screen notification
    Samsung One UI doesn't accept third-party widgets on the lock screen via
    the standard AppWidget keyguard category (Samsung's FaceWidget API is
    the alternative, but it's private/undocumented and likely fragile). The
    standard cross-OEM way to surface ambient sensor data on the lock screen
    is a low-importance persistent notification, which Samsung shows on the
    lock screen by default.
    Configures the notification as:
    - IMPORTANCE_LOW channel (silent, no heads-up)
    - setOngoing(true) so it can't be swiped away
    - VISIBILITY_PUBLIC so it shows full content on the lock screen
    - setOnlyAlertOnce(true) so updates don't pulse
    Lives in its own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
2026-06-18 Redesign widget to mimic the e-paper display layout
    Replaces the generic key/value list rendering with the same fixed
    layout the firmware draws on the e-paper: temperature top-left,
    humidity top-right, big CO2 reading in the centre, battery
    bottom-left, "CO2 (ppm)" label bottom-right, with a small footer for
    status/timestamp. Colours flipped to white-on-black to match the
    paper-card aesthetic of the e-paper.
    Widget sizing tuned for a 2x2 cell target with floor down to 110dp so
    the user can still shrink it on the home screen. widget_row layout is
    no longer used and removed.
2026-06-18 Add Settings screen with dark/light widget toggle
    Replaces MainActivity's static info TextView with a real settings UI
    hosting an "Air Monitor" header, the setup hint, and a Settings
    section with the first toggle: Dark widget.
    Theming pipeline:
    - colors.xml exposes both light and dark palettes
    - Two background drawables (widget_background_light, widget_background_dark)
    - AppSettings encapsulates the boolean in SharedPreferences
    - WidgetState reads it at render time, swapping the background
    resource and every text colour via RemoteViews
    Toggling the switch immediately re-renders any placed widget. Light
    remains the default (paper-card aesthetic from the previous commit).
    Activity layout u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
2026-06-18 Add today's history graph to the activity
    Records every received reading to a 24h-retention JSON store and shows
    today's measurements (00:00 → 24:00) in a single graph pinned to the
    bottom of the activity at 50% of screen height. Three series plotted as
    small dots on a shared canvas with fixed Y ranges per variable:
    - CO2 0–2000 ppm (red)
    - Temp 0–40 °C (orange)
    - Humidity 0–100 % (blue)
    24 hourly vertical gridlines, 4 horizontal gridlines at 25/50/75/100 %
    of range, each annotated with three rotated values (one per series,
    color-coded) along the left edge. Legend below the graph identifies
    each colour.
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2026-06-18 Make the graph horizontally zoomable and pannable
    Adds pinch zoom (around the pinch focus), drag pan, and double-tap to
    reset on HistoryGraphView. Y-axis remains locked at each series' fixed
    0 → max range; only the X-axis viewport changes. Viewport is bounded to
    today's 00:00–24:00 window and to a 5-minute minimum span.
    Time grid lines and x-axis labels adapt to the visible span — hourly
    ticks at 24h, 5-minute ticks at 1h zoom, etc. — and the time label
    format switches between HH and HH:MM as the resolution warrants.
    Times are rendered in local timezone (DST-aware via the timezone
    offset at the viewport midpoint).
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2026-06-19 Add a temperature offset setting
    The SCD41's onboard temperature reads several degrees above ambient
    because of self-heating from the surrounding electronics. Adds a
    Temperature offset row to Settings with a numeric input plus −/+
    steppers (0.1 °C per click), defaulting to +4.0 °C.
    The offset is stored raw and applied at every display site —
    WidgetState.formatTemperature, ReadingNotification.text, and the
    history graph's temperature series — so stored history is unaffected
    and changing the offset later corrects past data on redraw.
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2026-06-20 Make the e-paper display optional via DISPLAY_ENABLED flag
    For sensor-only units (no e-paper wired), the firmware was hanging in
    display.init() waiting forever on a floating BUSY pin — Serial would
    come up but nothing past that point ran, USB-Serial/JTAG kept getting
    reset by the watchdog. Adds a constexpr bool flag at the top of the
    file; flip to false for no-display builds and every display call
    (SPI.begin, init, setRotation, the firstBoot full-window clear,
    writeScreenBufferAgain, hibernate, the SPI.end on the way to sleep,
    showStatus, updateDisplay) is elided.
    if constexpr keeps the unused branch out of the binary entirely.
2026-06-20 Include esp_reset_reason in the beacon as a status byte
    Inserts a one-byte status field at offset 1 of the manufacturer-data
    payload (so absolute byte 3 of the AD, right after the version), holding
    the raw esp_reset_reason_t. After a normal deep-sleep wake the value is
    8 (ESP_RST_DEEPSLEEP); on any cold boot — power-on, brownout, panic,
    watchdog — it's the corresponding enum value. The app will use this to
    fire a heads-up notification when the chip rebooted unexpectedly.
    Breaks the protocol — CO2/temp/RH/bat all shift one byte later — but
    we're still prototyping; no backwards compatibility needed.
    README updated with the new payload layout and a status-value table
    covering every re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
2026-06-20 Split activity into Graph / Settings tabs with current-value strip
    Hand-built bottom navigation bar with two cells (📊 Graph / ⚙️ Settings).
    The content area is a FrameLayout that flips one tab's visibility off
    when the other is selected. Selected cell shows bold + full-strength
    text; the other dims. No external dependency added — vanilla LinearLayout
    and View.VISIBLE/GONE.
    Graph tab is no longer pinned to 50% of the screen — it fills its tab.
    Settings tab now scrolls (a few rows already exceed shorter screens).
    Graph tab gets the same "Air Monitor" title + divider header as the
    Settings tab, plus a current-values strip just under the divider:
    4 columns (CO2, Temp, RH, Bat) with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
2026-06-20 Add a Log tab + catch the parser up to the v2 payload layout
    Parser:
    - BEACON_PAYLOAD_LEN bumped to 8
    - payload[1] is now read as status (esp_reset_reason_t); CO2/temp/RH/bat
    shifted to 2-3, 4-5, 6, 7 respectively
    - status is added to the JSON
    HistoryStore:
    - Entry gains battery (-1 if charging/unknown), charging, status fields,
    carried through append/read/write. Older on-disk entries default
    cleanly via JSONObject.optInt/optBoolean.
    UI:
    - Third bottom-bar cell (📜 Log)
    - New tab content: title + column-header strip + a ListView of
    HistoryStore.read() reversed so the most recent reading is on top
    - LogAdapter inflates a compact monospace row per entry, with reset
    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
2026-06-20 Tighten enclosure: cleaner screw posts, slotted vents
    Screws posts: bumped facet count from 10 to 20 (smoother walls), shaft
    radius up from 0.5 to 0.75, head pocket shifted to -0.1 with depth 1.5,
    top-cap mount on the +y side raised by 5 mm to match the box.
    Vents on the back face: switched from the dotted-grid hole pattern to
    hull-extruded slots — capsule-shaped slots running y=8 → y=26 across the
    five x positions, 1 mm radius. Lets more air through and prints
    cleaner.
    Front-face vent row narrowed from x=[-10..10] to x=[-6..6] so the row
    stays inside the e-paper window.
    [enclosure.scad, enclosure.stl]
2026-06-27 Tighten enclosure to hardware; add carabine hoop
    Trimmed the internal dimensions for a closer fit to the assembled
    PCB + battery stack, and added a hoop on the top edge so the device
    can be clipped to a bag with a carabiner.
    [enclosure.scad, enclosure.stl]
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2026-07-11 Extract e-paper handling into a Display class
    Fourth and last step of splitting firmware.ino into modules. The
    GxEPD2 panel object, the SPI + SSD1681 bring-up sequence, the pin
    constants, the layout constants, the rolling boot-status column, and
    the main-dashboard render all move into display.{h,cpp}. So do the
    SPI, GxEPD2, and Font includes.
    - Constructor takes a firstBoot bool and, when true, does the
    full-window clear + writeScreenBufferAgain sync needed to keep
    subsequent partial refreshes coherent.
    - Destructor releases SPI and floats MOSI to reduce sleep leakage.
    - Two methods: showStatus for the boot-diagnostic column and
    showReading for the main dashboard. sh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
    [display.cpp]
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2026-07-11 Split firmware into common library, display sketch, and led sketch stub
    Extract battery/ble/reset_reason/sensor into an Arduino library under
    common/. Move the current v1 sketch into display/, tracked as a rename
    so history follows. Add an led/ sketch that currently just deep-sleeps —
    hardware modules for the SK9822 LED, button, and explicit charging
    divider will follow.
    CMake now exposes build_display / flash_display / build_led / flash_led
    targets. The 'build' target still builds both.
    [app.cpp, battery.cpp, display.cpp]
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2026-09-12 Turn the LED variant into a real beacon; fix BLE re-init panic
    The LED sketch was a blink bring-up test. Rewrite it to mirror the
    display variant's measure → output → advertise → deep-sleep cycle, with
    the RGB LED standing in for the e-paper and the button as a wake source.
    - app.cpp: every cycle takes an SCD41 measurement, flashes a CO2-mapped
    colour (~1 s), and advertises the beacon. Wakes on the 5-min timer or a
    button press. Battery deep-sleeps between cycles; USB stays awake at a
    faint-blue idle and re-runs on timer/button. One press = one cycle
    (waits for button release so a hold can't re-trigger).
    - led.h: add green/yellow/orange/red CO2-band colours; keep green=D2,
    b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
    [app.cpp]
2026-09-23 LED: drive pins low at boot to kill blue-channel wake glow
    The blue channel (D7/GPIO20) glows faintly in the window between reset and
    LED setup on a battery wake. Driving all three LED pins low as the first
    firmware action in setup() closes most of that window.
    [app.cpp]
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2026-09-23 LED: drop redundant light-sleep wait after single-shot measurement
    measureSingleShot() already blocks the full ~5s conversion (delay(5000) in
    the driver), so the extra esp_light_sleep_start() for MEASURE_MS was a second
    5s wait for the same measurement. Remove it and fix the startMeasurement()
    doc comment, which wrongly claimed the call returns immediately.
    [app.cpp]
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2026-09-27 Sensor: disable auto self-calibration on first boot
    ASC assumes the sensor regularly sees fresh ~400ppm air and rebaselines
    toward it; in our infrequent single-shot use that drifts the reading. Disable
    ASC and persist it to the SCD41's EEPROM so it stays off across power cycles
    (the manual FRC path via calibrate() is now the calibration mechanism).
    Guarded read-before-write so the EEPROM is only written when ASC is actually
    still on, sparing its limited write endurance. Runs in the constructor's
    first-boot branch, already in idle mode after stopPeriodicMeasurement().
    [sensor.cpp]
